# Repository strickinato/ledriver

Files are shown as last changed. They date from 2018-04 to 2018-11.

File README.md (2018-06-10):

### LEDRIVER ###
Addressable lighting controller and accessories.

### Hardware ###
#### ledriver ####
(l-e-d river)
A teensy 3.2 versatile addressable lighting controller based on the OctoWS811 shield with lots of goodies.
- Wiznet module
- SDcard
- OLED screen
- UART breakouts
- Other clk+data output
- three buttons
- two pots
- one status led
- (piezo?? vibration detection tap tempo)

#### UI Board ####
Move pots, butons, OLED to a second poard with dedicated controller?

#### Todo ####
- Make sure teensy 3.5 fits...

#### RJPowerData ####
Connects to a ledriver board rj45 output and distributes the 4 channels of ws2811 with power.
- Fits 3.96mm and 5.08mm pitch connectors
- Fused output (microblades)
- LEDs after fuzes
- second 8p8c connector if not breaking out all the data lines.

## Firmware ##

https://forum.pjrc.com/threads/91-teensy-3-MAC-address

Sketch uses 70248 bytes (26%) of program storage space. Maximum is 262144 bytes.

### LED setup ###
Strategy : use a fixed number of LED per strips, config defines exacte number of LED per strip output. Then incomming buffers are spread to the correct slots.

#### Command System ####
- OSC based ?
- Control via serial
- network -> generate web interface?
- websocket
- osc
- map commands to dmx? brightness etc.

`/lr/brightness/ 255` -> BRIGHTNESS_CMD_BYTE + value

```
"dmx_map": {
        "0" : "/lr/brightness",
        "1" : "/lr/speed",
        "2" : "/lr/animation"
    }
```

##### Command List #####
- mode 2
- speed 255
- brightness 255
-

### webriver interface ###
Perhaps the controller should change the interface as needed. In example if set to SD card playback, populate a drop menu with names of saved animations.
- Make phone / desktop friendly.

#### LED lookup ####
- Lower Res feature? control 2 3 or 4 pixels as 1? or do in computer software...
- Add support for freeliner LED files!!

#### LED Packet ####
Reserve 2-3 bytes for controller specific info, such as :
- encode "lerp" timer and "beatCount".
- a packet type? (ramp to in X seconds);
- - command packet, append longer commands (ie save "sweetAnimation.ani");

#### Controller Commands ####
- Record animation
- play animation
- run test patterns
###### inbound
- `/record 1 (fileName)` make a filename if none provided
- `/record 0` stop recording
- `/bright 255`
- `/mode 2`
- `/speed 255`
- `/getinfo`
###### outbound

#### SD Card Saved animations
Somehow freeliner needs to to send its sync through Artnet, perhaps with sequence value?
SMPTE?
Or ArtTimeCode
Paire sequence number with lerp value?

#### Test Patterns ####
Dank test patterns for production tests.

#### config.json ####
SD card config file. Uses JSON now.
```
{

}
name=stjean
dhcp=true
ip=10.0.0.42
debug=oled
debug=Serial1/2/3
```
#### Mapping Assist ####
- Use up down button to select led,
- Set this led as the first of universe X
- Set the end?
#### Logging on SD ####
Save information as running time, errors, input frequency

#### Dependencies ####
- Ethernet
- FastLED
- SD
- SDconfigFile
- TeensyDMX

#### Optimisation ####
- between each frame pick one task from a list and increment.
    - (check websocket, check udp for OSC, ???)

### Bonus Round ###
- Its also a midi controller so you can control the software to control your controller.
- OSC controller too
- NTP time + rtc, scheduler, `schedule.scd`
- Weather
- OSC message printing on oled. Debug the network.
- pinging tool (ping list of hosts.txt)
- DMX controller,
- ArtNet controller
- DMX to usbMIDI, MIDI
- MIDI to DMX

<!-- ### Glossary ###
 - `template` set of parameters for animations, such as color and easing, templates are applied to `groups`
- `group` group of segments with a center point.
- -->
### Notes ###

##### DMX #####
- DMX+ 485A xlr pin 3 yellow
- DMX- 485B xlr pin 2 blue

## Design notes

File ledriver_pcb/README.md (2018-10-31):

### Le Driver ###
AKA LED River
Multi purpose LED driver board based on Teensy and OctoWS

#### Features ####
- MicroSD card reader
- WizNET adapter footprint
- DMX output and input?
- Multiple connector choice (RJ45, )
- Serial port for connecting to other board
- Potentiometers
- Buttons
- any extra pin breakout

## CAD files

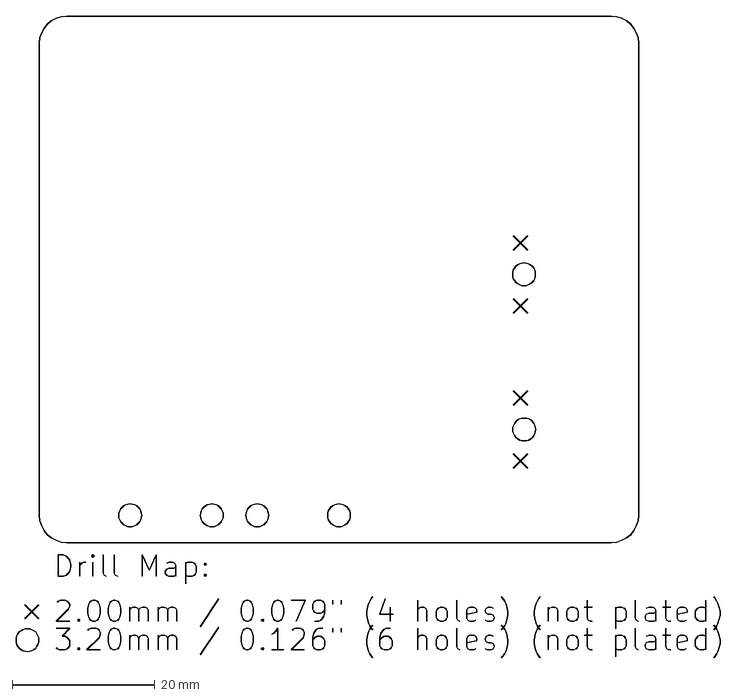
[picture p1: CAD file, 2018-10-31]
ledriver_pcb/output/#ledriver_pcb-NPTH-drl_map.dxf
98.5 x 89.8 mm

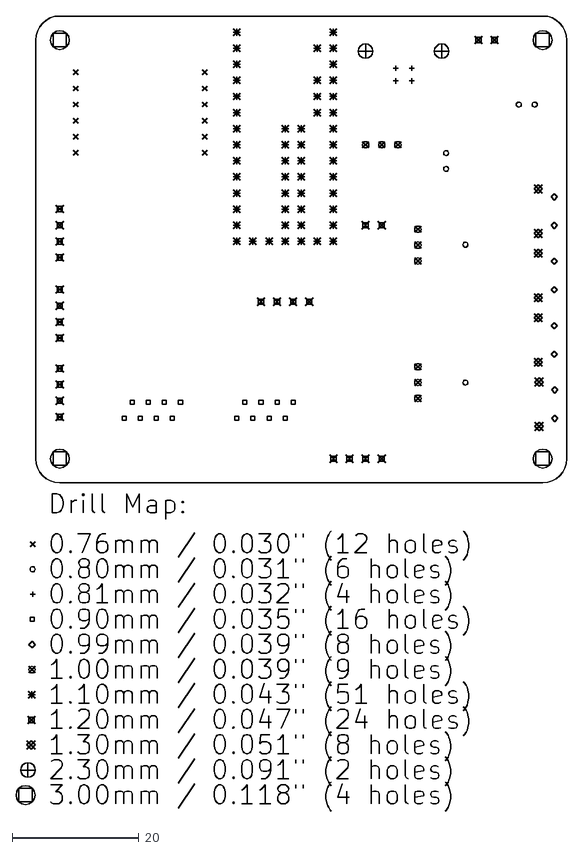
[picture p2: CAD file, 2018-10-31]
ledriver_pcb/output/ledriver_pcb-drl_map.dxf
86.9 x 125.4

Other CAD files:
ledriver_pcb/output/ledriver_pcb-NPTH-drl_map.dxf

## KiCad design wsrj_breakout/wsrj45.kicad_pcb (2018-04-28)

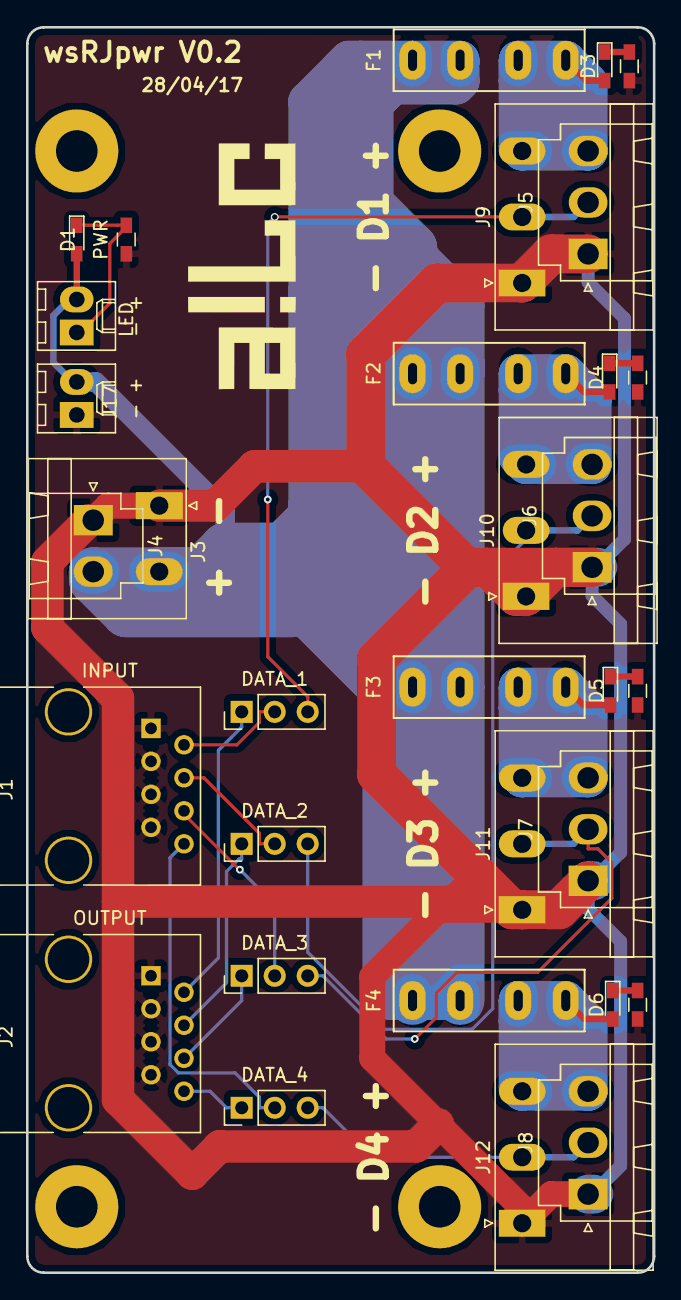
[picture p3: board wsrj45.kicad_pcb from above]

Board: 2 copper layers, 48.3 x 95.9 mm, 36 parts (0 on the bottom side), 23 nets.

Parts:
D1: PWR; LED_0603_HandSoldering
D3: PWR_1; LED_0603_HandSoldering
D4: PWR_2; LED_0603_HandSoldering
D5: PWR_3; LED_0603_HandSoldering
D6: PWR_4; LED_0603_HandSoldering
F1, F2, F3, F4: Fuse; MINI_FUSE_HOLDER
J1: INPUT; RJ45_8_54602-908LF
J2: OUTPUT; RJ45_8_54602-908LF
J3: DC_IN; PhoenixContact_MSTBA-G_02x5.08mm_Angled
J4: DC_IN; JST_VH_B2P-VH-B_2x3.96mm_Vertical
J5: DATA_1; JST_VH_B3P-VH_3x3.96mm_Vertical
J6: DATA_2; JST_VH_B3P-VH_3x3.96mm_Vertical
J7: DATA_3; JST_VH_B3P-VH_3x3.96mm_Vertical
J8: DATA_4; JST_VH_B3P-VH_3x3.96mm_Vertical
J9, J10, J11, J12: Conn_01x03; PhoenixContact_MSTBA-G_03x5.08mm_Angled
J13, J14, J15, J16: Conn_01x01; MountingHole_3.2mm_M3_Pad
J17: - +; Molex_KK-6410-02_02x2.54mm_Straight
J18: DATA_4; Socket_Strip_Straight_1x03_Pitch2.54mm
J19: DATA_3; Socket_Strip_Straight_1x03_Pitch2.54mm
J20: DATA_2; Socket_Strip_Straight_1x03_Pitch2.54mm
J21: DATA_1; Socket_Strip_Straight_1x03_Pitch2.54mm
LED: - +; Molex_KK-6410-02_02x2.54mm_Straight
R1, R2, R3, R4, R5: R; R_0603_HandSoldering

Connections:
/DATA_1: J5.2, J9.2, J21.3
/DATA_2: J6.2, J10.2, J20.3
/DATA_3: J7.2, J11.2, J19.3
/DATA_4: J8.2, J12.2, J18.3
/VCC_1: D3.2, F1.1, J5.3, J9.3
/VCC_2: D4.2, F2.1, J6.3, J10.3
/VCC_3: D5.2, F3.1, J7.3, J11.3
/VCC_4: D6.2, F4.1, J8.3, J12.3
GND: J1.1, J1.3, J1.5, J1.7, J2.1, J2.3, J2.5, J2.7, J3.1, J4.1, J5.1, J6.1, J7.1, J8.1, J9.1, J10.1, J11.1, J12.1, J17.1, R1.2, R2.2, R3.2, R4.2, R5.2
unnamed: D1.1, LED.1, R1.1
unnamed: D3.1, R2.1
unnamed: D4.1, R3.1
unnamed: D5.1, R4.1
unnamed: D6.1, R5.1
unnamed: J1.2, J21.2
unnamed: J1.4, J20.2
unnamed: J1.6, J19.2
unnamed: J1.8, J18.2
unnamed: J2.2, J21.1
unnamed: J2.4, J20.1
unnamed: J2.8, J18.1
unnamed: J2.6, J19.1
VCC: D1.2, F1.2, F2.2, F3.2, F4.2, J3.2, J4.2, J17.2, LED.2

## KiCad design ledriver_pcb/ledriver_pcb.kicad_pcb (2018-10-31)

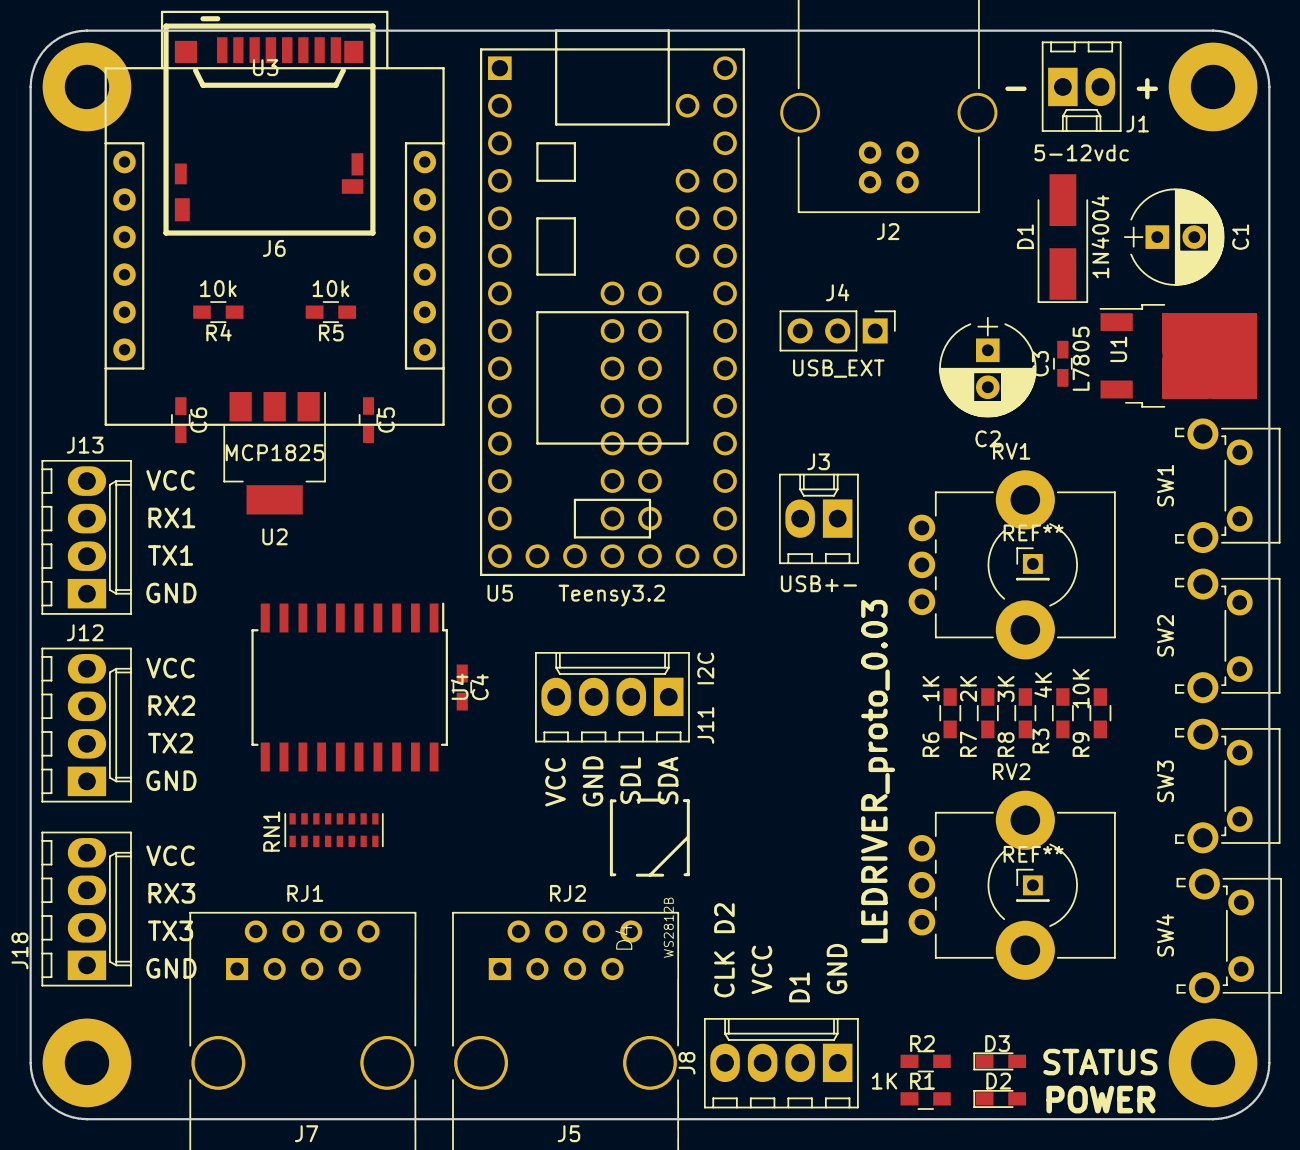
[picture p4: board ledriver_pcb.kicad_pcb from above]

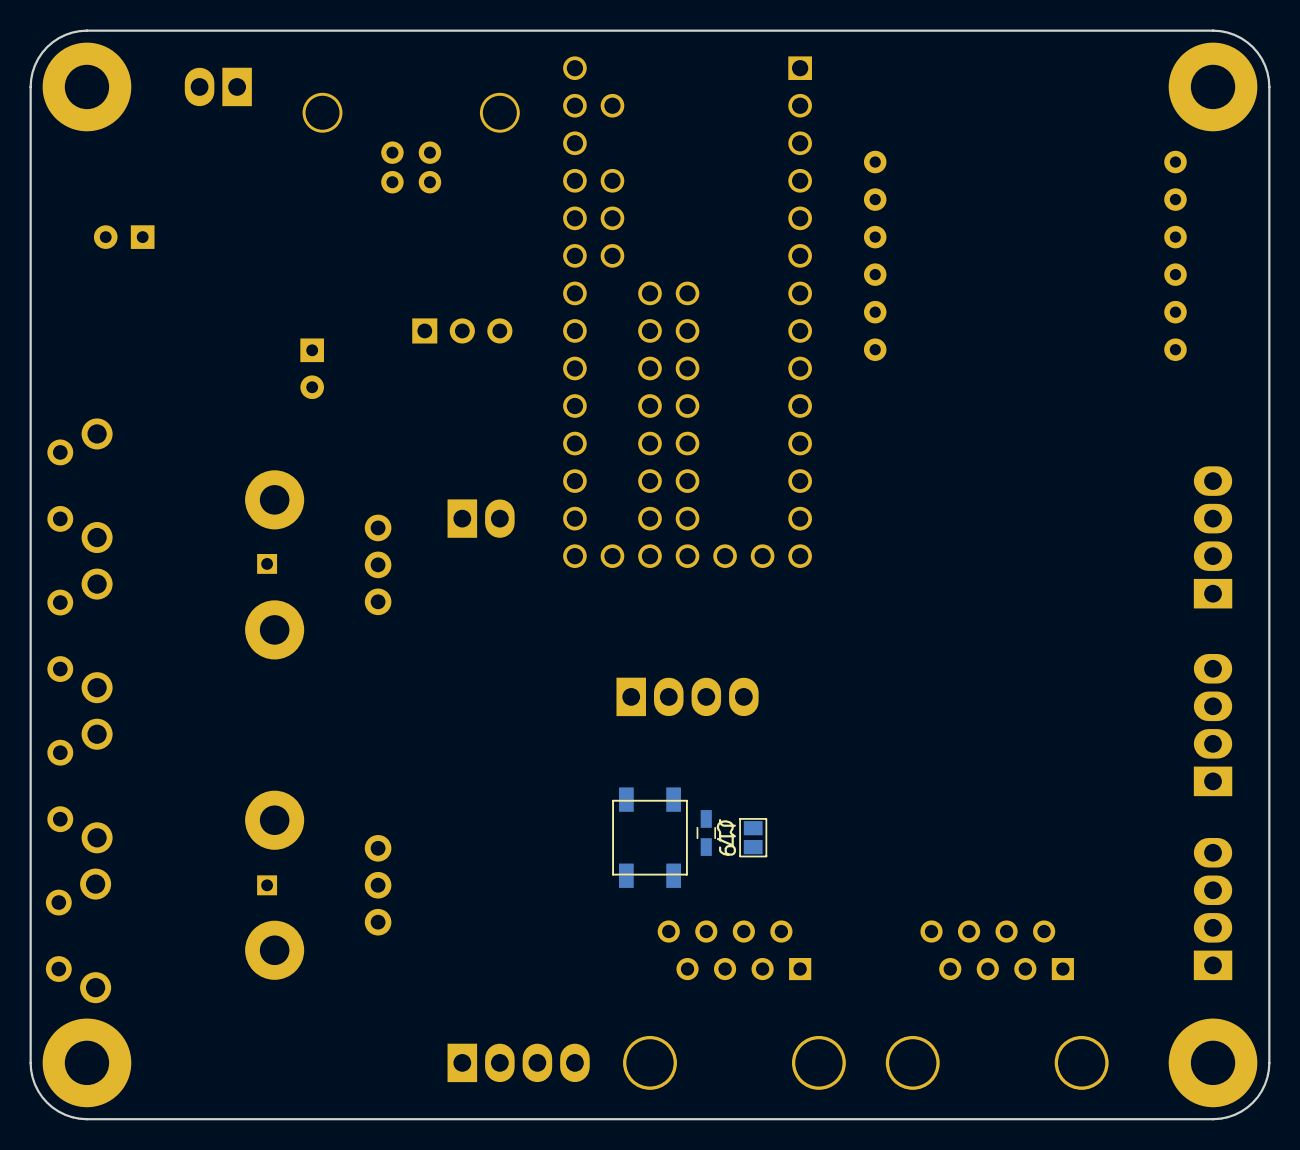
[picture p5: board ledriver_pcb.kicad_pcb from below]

Board: 2 copper layers, 83.8 x 73.7 mm, 49 parts (3 on the bottom side), 58 nets, no tracks yet.

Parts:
C1, C2: 47uF; CP_Radial_D6.3mm_P2.50mm
C3, C5, C6: 0.1uF; C_0603_HandSoldering
C4: 1uf; C_0603_HandSoldering
C7: C; C_0603_HandSoldering
D1: 1N4004; D_SMA_Handsoldering
D2: POWER; LED_0603_HandSoldering
D3: LED; LED_0603_HandSoldering
D4: WS2812B
J1: 5-12vdc; Molex_KK-6410-02_02x2.54mm_Straight
J2: USB_B
J3: USB+-; Molex_KK-6410-02_02x2.54mm_Straight
J4: USB_EXT; Pin_Header_Straight_1x03_Pitch2.54mm
J5: RJ2; RJ45_8_54602-908LF
J6: CONN-114-00841-68-MICROSD; AMPHENOL-114-00841-68
J7: RJ1; RJ45_8_54602-908LF
J8: led_out_clk; Molex_KK-6410-04_04x2.54mm_Straight
J11: I2C; Molex_KK-6410-04_04x2.54mm_Straight
J12: Serial2; Molex_KK-6410-04_04x2.54mm_Straight
J13: Serial1; Molex_KK-6410-04_04x2.54mm_Straight
J14, J15, J16, J17: M3; MountingHole_3mm_Pad
J18: Serial3; Molex_KK-6410-04_04x2.54mm_Straight
J19: underglow; GS2
R1, R2, R6: 1K; R_0603_HandSoldering
R3: 4K; R_0603_HandSoldering
R4, R5: 10k; R_0603_HandSoldering
R7: 2K; R_0603_HandSoldering
R8: 3K; R_0603_HandSoldering
R9: 10K; R_0603_HandSoldering
RN1: R_100; R_Cat16-8
RV1, RV2: POT; Potentiometer_Bourns_PTV09A-1_Horizontal
SW1, SW2, SW3, SW4: SW_SPST; SW_Tactile_SPST_Angled_PTS645Vx39-2LFS
U1: L7805; TO-252-2
U2: MCP1825; SOT-223-3_TabPin2
U3: WIZ820IO
U4: 74HC245; SOIC-20W_7.5x12.8mm_Pitch1.27mm
U5: Teensy3.2; Teensy30_31_32_LC

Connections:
+3V3: R3.1, R6.1, R7.1, R8.1, RV1.1, RV2.1, U5.31
+12V: D1.2, J1.2
/BUTTONS: R9.2, SW1.1, SW2.1, SW3.1, SW4.1, U5.24
/DATA_1_PIN_2: U4.2, U5.4
/DATA_2_PIN_14: U4.3, U5.21
/DATA_3_PIN_7: J18.3, U4.4, U5.9
/DATA_4_PIN_8: J18.2, U4.5, U5.10
/DATA_5_PIN_6: U4.6, U5.8
/DATA_6_PIN_20: U4.7, U5.27
/DATA_7_PIN_21: U4.8, U5.28
/DATA_8_PIN_5: U4.9, U5.7
/I2C_SCL: J11.2, U5.26
/I2C_SDA: J11.1, U5.25
/POT1: RV1.2, U5.22
/POT2: RV2.2, U5.23
/RX1: J13.3, U5.2
/RX2: J12.3, U5.11
/SPI_CS_SDCARD: J6.2, R5.2, U5.5
/SPI_CS_WIZ: R4.2, U3.5, U5.6
/SPI_DIN: J6.7, U3.7, U5.14
/SPI_DOUT: J6.3, U3.3, U5.13
/SPI_SCK: J6.5, U3.4, U5.20
/STATUS: D3.2, U5.29
/TX1: J13.2, U5.3
/TX2: J12.2, U5.12
/WIZ_RESET: U3.8, U5.30
GND: C1.2, C2.2, C3.2, C4.2, C5.2, C6.2, C7.2, D4.3, J1.1, J2.4, J2.5, J5.1, J5.3, J5.5, J5.7, J6.6, J6.11, J7.1, J7.3, J7.5, J7.7, J8.1, J11.3, J12.1, J13.1, J18.1, R1.2, R2.1, U1.2, U2.2, U3.1, U3.2, U3.12, U4.10, U4.19, U5.1
GNDA: R9.1, RV1.3, RV2.3, U5.32
unnamed: C1.1, D1.1, U1.1
unnamed: C2.1, C3.1, J4.1, U1.3
unnamed: C6.1, J6.4, R4.1, R5.1, U2.3, U3.10, U3.11
unnamed: D2.1, R1.1
unnamed: D3.1, R2.2
unnamed: D4.4, J19.1
unnamed: J2.1, J4.3
unnamed: J2.2, J3.1
unnamed: J2.3, J3.2
unnamed: J5.2, RN1.12
unnamed: J5.4, RN1.11
unnamed: J5.6, RN1.10
unnamed: J5.8, RN1.9
unnamed: J7.4, J8.4, RN1.15
unnamed: J7.6, RN1.14
unnamed: J7.8, RN1.13
unnamed: J7.2, J8.2, J19.2, RN1.16
unnamed: R3.2, SW4.2
unnamed: R6.2, SW1.2
unnamed: R7.2, SW2.2
unnamed: R8.2, SW3.2
unnamed: RN1.1, U4.18
unnamed: RN1.2, U4.17
unnamed: RN1.3, U4.16
unnamed: RN1.4, U4.15
unnamed: RN1.5, U4.14
unnamed: RN1.6, U4.13
unnamed: RN1.7, U4.12
unnamed: RN1.8, U4.11
VCC: C4.1, C5.1, C7.1, D2.2, D4.1, J4.2, J8.3, J11.4, J12.4, J13.4, J18.4, U2.1, U4.1, U4.20, U5.33

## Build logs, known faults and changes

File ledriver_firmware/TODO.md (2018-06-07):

### Firmware todo ###
- Set artnet poll reply numports to universe count for CRGB buffer
- webserver
    - client.println("Access-Control-Allow-Origin: \*");

- Arduino-Websocket with Stream / print capabilities?

#### debug ####
- `view.println("- statement");` with debug_level > 0
- `view.println("-- explicit statement");` with debug_level > 0
- `view.println("! error message");` error with debug level > 0
- `view.println("!! serious error message");` rerror with debug level > 1

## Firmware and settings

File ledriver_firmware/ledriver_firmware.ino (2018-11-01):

/**
 * ##copyright##
 * See LICENSE.md
 *
 * @author    Maxime Damecour (http://nnvtn.ca)
 * @version   0.4
 * @since     2017-01-16
 */
 // FastLED


#include "LEDriver.h"
#include "Ethernet.h"

LEDriver ledriver;
// these need to be initialised here unfortunatlyf
EthernetServer serverForSocket(80);
TeensyDmx dmx1(Serial1);
// TeensyDmx dmx2(Serial2);
TeensyDmx dmx3(Serial3);

void setup(){
    Serial.begin(115200);
    ledriver.dmxOne.dmx = &dmx1;
    ledriver.dmxThree.dmx = &dmx3;

    // initialise the system
    ledriver.begin();
    // set the callback
    ledriver.customMode.setCallback(custom);
    ledriver.setCallback(updateCallback);
}

void loop(){
    // runs once
    ledriver.runWithWebsocket(&serverForSocket);
    // otherwise :
    // ledriver.update();
}

void updateCallback(){
    
}


// custom mode's update method callback, add your own animation without much digging.
void custom(){
    for(int i = 0; i < 16; i++){
        ledriver.leds[i] = CHSV(pow((millis()%2000)/2000.0, 3)*255, 255, 255);
        // leds[i] = CRGB(millis()/10 % 255,0,0);
    }
    FastLED.show();
}

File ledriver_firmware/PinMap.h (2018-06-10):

#ifndef PinMap_h
#define PinMap_h

// All the pins
#define RX1_PIN 0
#define TX1_PIN 1
#define DATA_1_PIN  2
// #define SDCARD_CS_PIN 3
// #define WIZNET_CS_PIN 4
#define SDCARD_CS_PIN 3
#define WIZNET_CS_PIN 10
#define DATA_8_PIN  5
#define DATA_5_PIN  6
#define DATA_3_PIN  7
#define DATA_4_PIN  8
#define RX2_PIN 9
#define TX2_PIN 10
#define SPI_DOUT_PIN 11
#define SPI_DIN_PIN 12

#define SPI_CLK_PIN 13
#define DATA_2_PIN 14
#define POT1_PIN 15
#define POT2_PIN 16
#define BUTTON_PIN 17
#define I2C_SDA_PIN 18
#define I2C_SCL_PIN 19
#define DATA_6_PIN 20
#define DATA_7_PIN 21
#define STATUS_LED_PIN 22
#define WIZNET_RESET_PIN 23

#endif

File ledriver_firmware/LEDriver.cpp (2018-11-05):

// #define BOARD_REV 002
#define BOARD_REV 003
#include "LEDriver.h"

#define NO_POTS 0

LEDriver::LEDriver() {
    modePointers[DEMO_MODE] = &demoMode;
    modePointers[ARTNET_MODE] = &artnetMode;
    modePointers[SERIAL_MODE] = &serialMode;
    modePointers[TEST_MODE] = &testMode;
    modePointers[CUSTOM_MODE] = &customMode;
    modePointers[SDPLAY_MODE] = &sdPlaybackMode;
    modePointers[FUN_MODE] = &funMode;
    modePointers[WEBSOCKET_CONTROL_MODE] = &websocketControlMode;
}

void LEDriver::begin(){
    view.begin();
    view.printf("ledriver V%f\n", VERSION);

    // fetch config
    if(!SD.begin(SDCARD_CS_PIN)){
        view.println(F("no SDcard..."));
    }
    else {
        loadConfigFile(CONFIG_FILE);
        loadConfigFile(LED_CONFIG_FILE);
        loadConfigFile(DMX_CONFIG_FILE);
    }

    dataBuffer.begin();
    // setup buffer
    leds = dataBuffer.getLEDs();
    Mode::leds = dataBuffer.getLEDs();
    Mode::ledCount = dataBuffer.ledCount;

    // setup some pins
    pinMode(STATUS_LED_PIN, OUTPUT);

    // setup modes
    artnetMode.setup();

    // enable FastLED
    dataBuffer.enableFastLED(ledOutputMode, ledColorOrder);
    // if(ledOutputMode == FAST_OCTO){
    //     if(debug_level > 0) view.println("- fastocto go");
    // } else if (ledOutputMode == FAST_WS2801) {
    //     dataBuffer.enableFastLED(WS2801);
    //     if(debug_level > 0) view.println("- fastws go");
    // }

    network.reset();

    // init network, may take a moment
    if(debug_level > 0) view.println(F("- init network"));
    network.begin();
    // print resulting network information
    if(debug_level > 0){
        if(network.useDHCP){
            // view.printf("DHCP %i.%i.%i.%i \n", network.ip[0], network.ip[1], network.ip[2], network.ip[3]);
            view.print("DHCP ");
            view.println(network.ipAddress);
        }
        else {
            // view.printf("STATIC %i.%i.%i.%i \n", network.ip[0], network.ip[1], network.ip[2], network.ip[3]);
            view.print("STATIC ");
            view.println(network.ipAddress);
        }
    }

    // SD.exists("config.jso");

    frameCount = 0;
    fpsCount     = 0;
    timeStamp = millis();\
    // setMode(FUN_MODE);//ARTNET_MODE);//MO_MODE);
}

///////////////////////////////////////////////////////////////////////////////
// Messaging
///////////////////////////////////////////////////////////////////////////////

// this is needed to keep the websocket connection active and output to leds
void LEDriver::runWithWebsocket(EthernetServer * serverForSocket){
    EthernetClient client = serverForSocket->available();
    if(client.connected() && webSocketServer.handshake(client)){
        if(debug_level > 0) view.println(F("- ws cnnctn"));
        // on new connection push config :
        pushConfig();
        while(client.connected()){
            checkUdpForOSC();
            checkWebsocket();
            // call the regular update
            update();
        }
        if(debug_level > 0) view.println(F("! ws dscnct"));
        delay(100);
        client.stop();
    }
    else {
        update();
    }
}

void LEDriver::checkUdpForOSC(){
    int _sz = network.oscUDP.parsePacket();
    if(_sz > 0){
        char _array[_sz];
        network.oscUDP.read(_array, _sz);
        receiveOSC((uint8_t *)_array, _sz);
    }
}

void LEDriver::checkWebsocket(){
    socket_data = webSocketServer.getData();
    if(socket_data.length()> 0){
      //if(debug_level > 1) view.println(_data);
        receiveJson(socket_data.c_str(), socket_data.length());
        // webSocketServer.sendData("ahhaha");
    }
}

// parse river_setup.json file in order to make menus for buttons and oled??
void LEDriver::receiveJson(const char * _received, size_t _size){
    StaticJsonBuffer<JSON_BUFFER_SIZE> jsonBuffer;

    view.println("RECEIVING JSON!!");
    if(_size > JSON_BUFFER_SIZE) {
        view.println("! JSON buffer size to small");
        return;
    }

    JsonObject &root = jsonBuffer.parseObject(_received);
    if(root.success()){
        view.println("WE GOT THE GOOD STUFF!");
        if(debug_level > 1){
            // view.println("- receivedJson");
            // root.printTo(view);
        }
        if(root.containsKey("config")){
            saveConfigFile(root, CONFIG_FILE);
        }
        else if(root.containsKey("leds")){
            saveConfigFile(root, LED_CONFIG_FILE);
        }
        else if(root.containsKey("DMX")){
            saveConfigFile(root, DMX_CONFIG_FILE);
        }
        else if(root.containsKey("funmode")){
            JsonObject & mode = root["funmode"];
            if(mode.containsKey("colorA")){
                long c = mode["colorA"];
                funMode.colorA = (CRGB)c;
            }
            if(mode.containsKey("speed")){
                funMode.speed = mode["speed"];
            }
            if(mode.containsKey("super")){
                funMode.super = mode["super"];
            }
            if(mode.containsKey("flash")){
                funMode.flash = mode["flash"];
            }
        }
    }
}


void LEDriver::receiveOSC(uint8_t * _mess, uint8_t _sz){
    OSCMessage messageIn;
    messageIn.fill(_mess, _sz);

    if(!messageIn.hasError()){
        if(messageIn.match("/record")){
            // view.printf("set bright %i \n", messageIn.getString(0));
        }
        else {
            view.printf("not match %i \n", messageIn.getInt(0));
        }
    }
    else {
        if(debug_level > 0) view.printf("osc error : %i \n",messageIn.getError());
    }
}

void sendFPS(){
    // OSCMessage msg("/fps");
    // msg.add((int32_t) fps);
}

///////////////////////////////////////////////////////////////////////////////
// command parsing
///////////////////////////////////////////////////////////////////////////////

void LEDriver::receiveCommand(uint8_t _cmd, uint8_t _val){
    // view.printf("received commend %i %i", _cmd, _val);
    switch(_cmd){
        case SET_MODE_CMD:
            setMode(_val);
            break;
        default :
            modePointers[currentMode]->receiveCommand(_cmd, _val);
        // case
    }
}


///////////////////////////////////////////////////////////////////////////////
// Update
///////////////////////////////////////////////////////////////////////////////
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

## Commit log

2018-01-11 first prototype ledRiver
    [ledriver_pcb.kicad_pcb, ledriver_pcb.sch]
2018-01-12 new ledriver layout
    [ledriver_pcb.kicad_pcb, ledriver_pcb.sch]
2018-01-26 board detween v02 and v03
    [ledriver_pcb.kicad_pcb, ledriver_pcb.sch]
2018-02-19 moving right along
    [ledriver_pcb.kicad_pcb, ledriver_pcb.sch]
2018-04-05 added Ethernet.init(pin)
2018-04-28 pre wsrj45 data ligne fix
    [wsrj45.kicad_pcb, wsrj45.sch]
2018-04-28 v02 of power distribution
    [wsrj45.kicad_pcb, wsrj45.sch]
2018-05-18 pre switching to arduino-json
2018-05-18 unsing teensyMAC and renamed View
2018-05-20 basic socket connection
2018-05-27 compiles, but crashes on startup
    [Defaults.h, LEDriver.cpp, ledriver_firmware.ino]
2018-05-28 changed led SPI output to use pin 7 and 14, not reflected in layout
    [ledriver_pcb.kicad_pcb, ledriver_pcb.sch]
2018-06-10 swapping a few pins to fix ehternet SPI CS thing
    [ledriver_pcb.sch]
2018-06-13 divided setup into config, led, and dmx
2018-11-01 added ws2801 leds, not quite working....
2018-11-01 fixed zero indexing bug with artnet, ws2801 works with artnet
    [LEDriver.cpp, Mode.cpp]
2018-11-05 Parse the websocket data to drive LEDs
2018-11-05 work to create a separate Mode for receiving LED data via websocket
2018-11-05 bunchof debugging because PARSING of incoming JSON is NOT WORKING!
    [LEDriver.cpp, Mode.cpp]
